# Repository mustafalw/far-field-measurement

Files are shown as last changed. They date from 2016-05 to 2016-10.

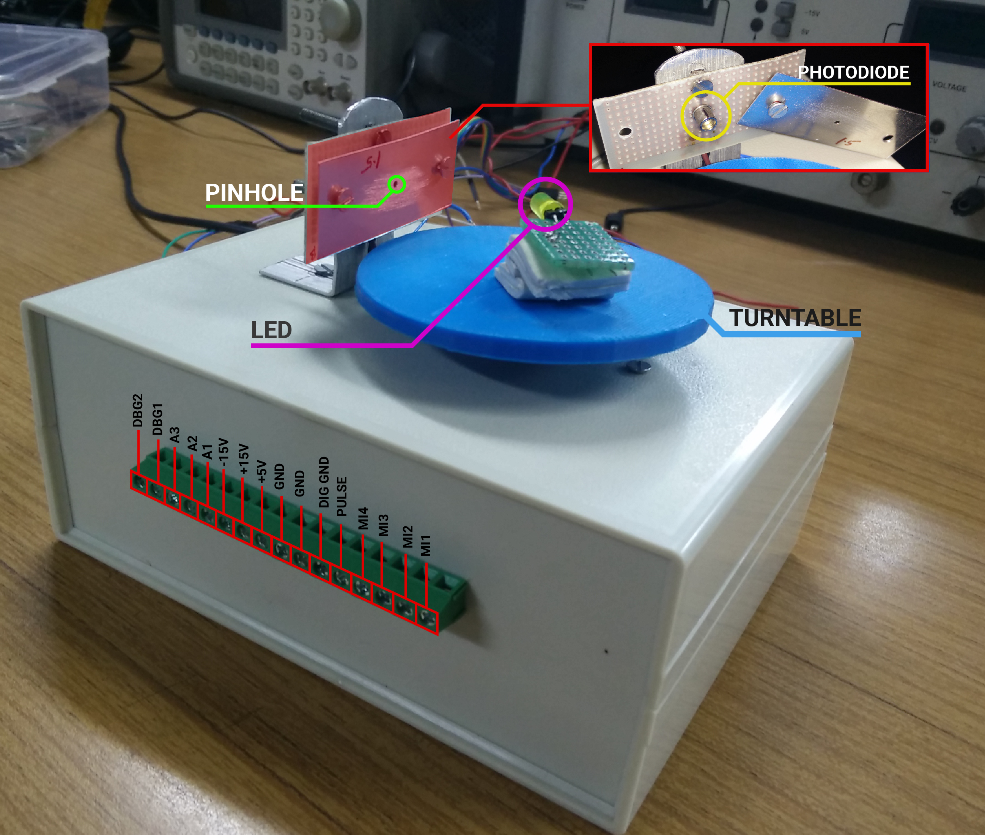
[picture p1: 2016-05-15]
outerview.jpg

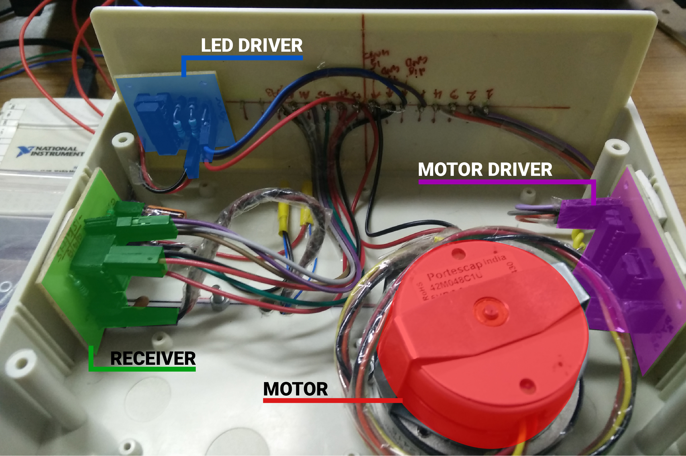
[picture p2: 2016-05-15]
innerview.jpg

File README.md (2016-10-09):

# far-field-measurement
This is our EE344 - Electronics Design Lab (EDL) project to build an apparatus for far field measurement of optical sources

A physical apparatus has been designed (a couple of pictures of the same are also there in the repository) to measure the far field angular radiation profile of optical sources like LEDs and laser diodes. The repository contains the comprehensive report, presentation, PCB designs, SPICE designs, LabVIEW codes and the final measurements. In addition, the video demonstrating the working of the apparatus can be found here: https://drive.google.com/open?id=0BwXnf3wcw68YSDE1a096Rm54bTg

Thanks!

Mustafa, Jashan and Deepak

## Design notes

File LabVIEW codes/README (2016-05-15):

Far Field Measurement of Optical Sources

The .vi files present in the "LabVIEW codes" folder require LabVIEW 2014 to run. Other details about pin configuration are provided in the report.

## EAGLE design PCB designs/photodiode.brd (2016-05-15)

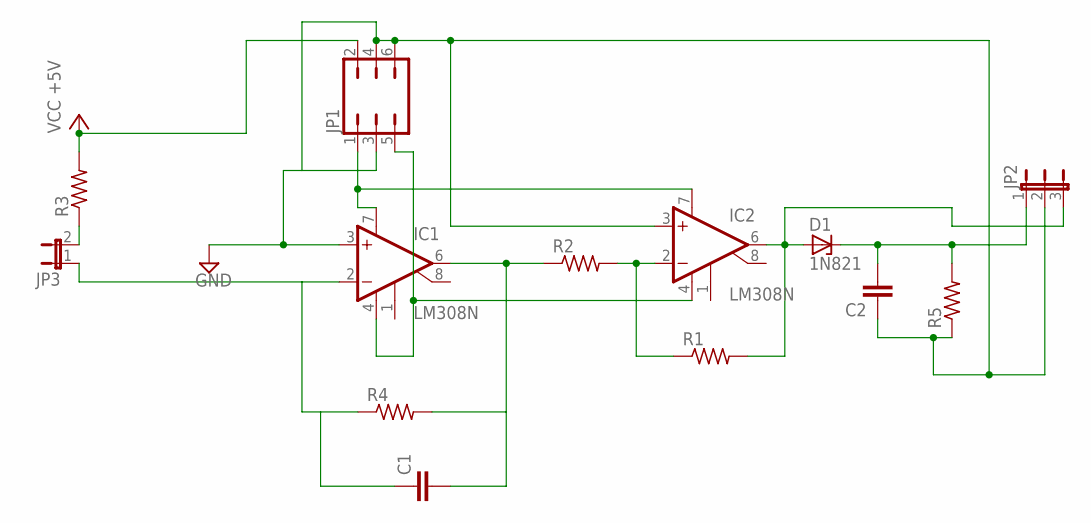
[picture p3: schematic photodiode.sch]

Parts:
C1, C2: C-EU025-024X044; C025-024X044
D1: 1N821; DO35Z10
IC1, IC2: LM308N; DIL08
JP1: JP3Q
JP2: JP2E; JP2
JP3: JP1E; JP1
R1, R2, R3, R4, R5: R-US_0207/10; 0207/10

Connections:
GND: C2.1, IC1.3 (+IN), IC2.3 (+IN), JP1.3, JP1.4, JP1.6, JP2.2, R5.1
unnamed: JP3.2, R3.1
unnamed: C1.1, IC1.2 (-IN), JP3.1, R4.1
unnamed: C1.2, IC1.6 (OUT), R2.1, R4.2
unnamed: IC1.7 (V+), IC2.7 (V+), JP1.1
unnamed: D1.A, IC2.6 (OUT), JP2.3, R1.2
unnamed: IC1.4 (V-), IC2.4 (V-), JP1.5
unnamed: C2.2, D1.C, JP2.1, R5.2
unnamed: IC2.2 (-IN), R1.1, R2.2
VCC: JP1.2, R3.2

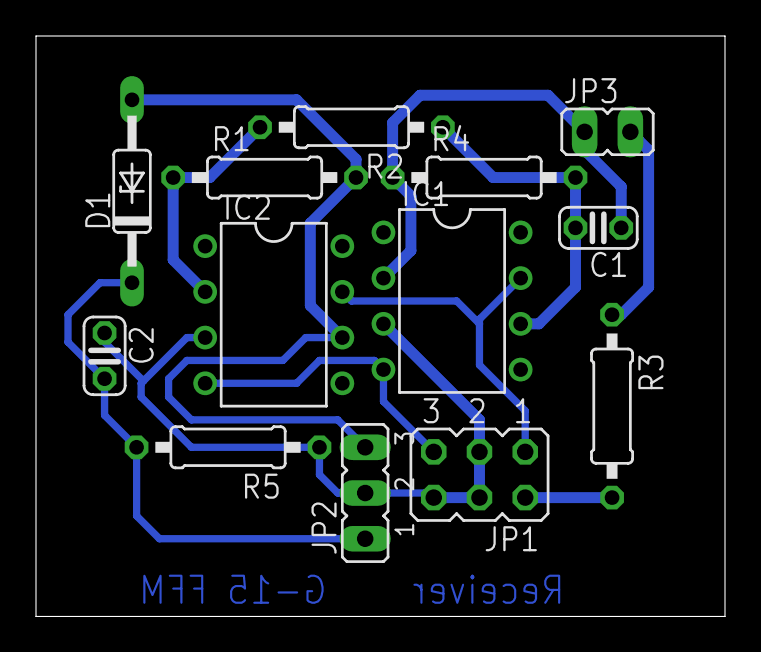
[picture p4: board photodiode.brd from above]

Board: 2 copper layers, 38.3 x 32.2 mm, 13 parts (0 on the bottom side), 10 nets.

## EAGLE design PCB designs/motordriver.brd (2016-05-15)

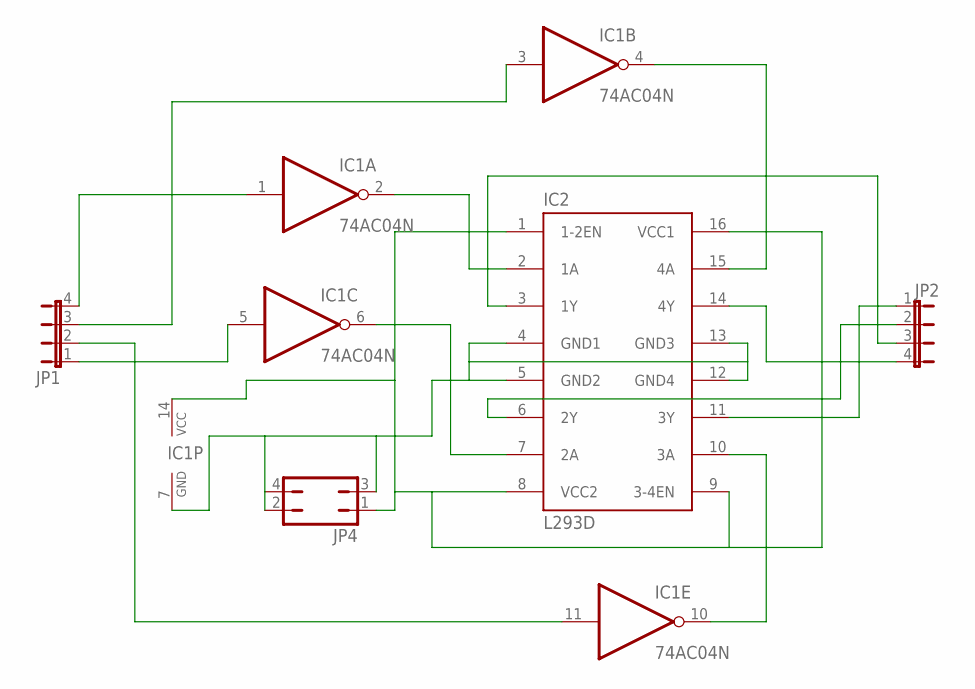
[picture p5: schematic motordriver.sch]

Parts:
IC1: 74AC04N; DIL14
IC2: L293D; DIL16
JP1, JP2: JP4E; JP4
JP4: JP2Q

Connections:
unnamed: IC1.1 (I), JP1.4
unnamed: IC1.5 (I), JP1.1
unnamed: IC1.3 (I), JP1.3
unnamed: IC1.2 (O), IC2.2 (1A)
unnamed: IC1.6 (O), IC2.7 (2A)
unnamed: IC1.4 (O), IC2.15 (4A)
unnamed: IC1.10 (O), IC2.10 (3A)
unnamed: IC2.3 (1Y), JP2.3
unnamed: IC2.6 (2Y), JP2.2
unnamed: IC2.11 (3Y), JP2.1
unnamed: IC2.14 (4Y), JP2.4
unnamed: IC1.11 (I), JP1.2
unnamed: IC1.14 (VCC), IC2.1 (1-2EN), IC2.8 (VCC2), IC2.9 (3-4EN), IC2.16 (VCC1), JP4.1
unnamed: IC1.7 (GND), IC2.4 (GND1), IC2.5 (GND2), IC2.12 (GND4), IC2.13 (GND3), JP4.2, JP4.3, JP4.4

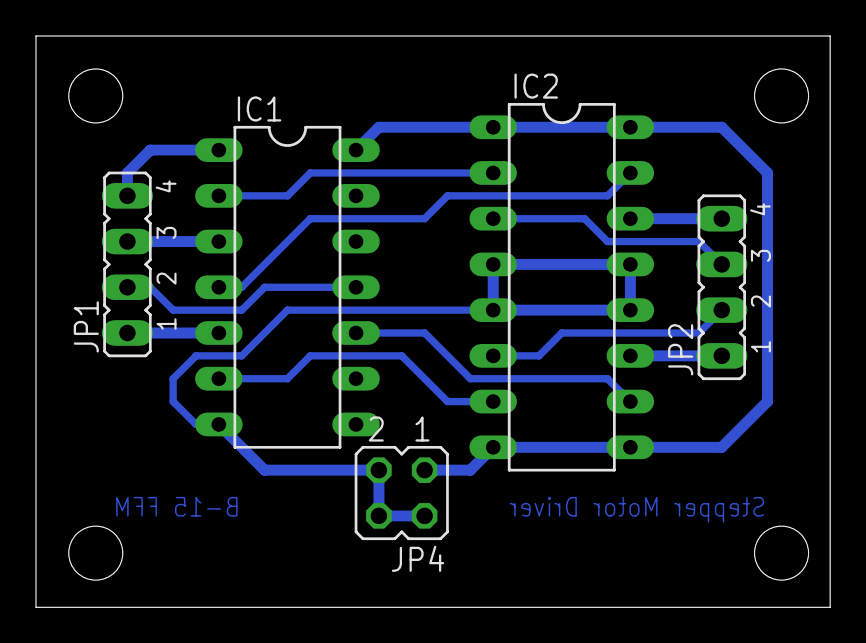
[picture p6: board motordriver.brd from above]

Board: 2 copper layers, 44.1 x 31.7 mm, 5 parts (0 on the bottom side), 14 nets.

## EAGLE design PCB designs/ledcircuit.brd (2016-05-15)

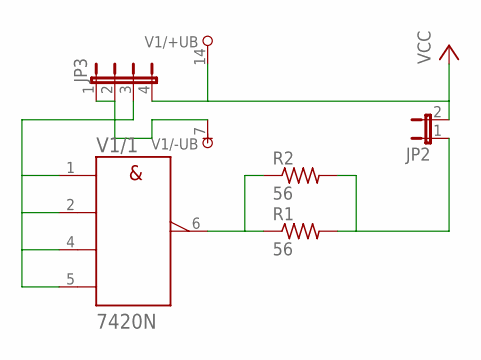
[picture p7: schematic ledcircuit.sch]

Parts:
JP2: JP1E; JP1
JP3: JP4E; JP4
R1, R2: 56; 0207/10
V1: 7420N; DIL14

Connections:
unnamed: R1.1, R2.1, V1.6 (Y)
unnamed: JP2.1, R1.2, R2.2
unnamed: JP3.3, V1.1 (A), V1.2 (B), V1.4 (C), V1.5 (D)
unnamed: JP3.1, JP3.2, V1.7 (-UB)
VCC: JP2.2, JP3.4, V1.14 (+UB)

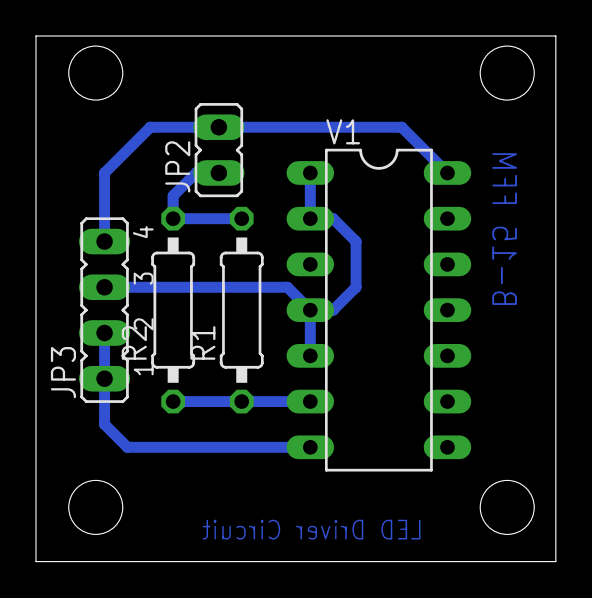
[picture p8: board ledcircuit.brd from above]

Board: 2 copper layers, 28.9 x 29.2 mm, 5 parts (0 on the bottom side), 5 nets.
